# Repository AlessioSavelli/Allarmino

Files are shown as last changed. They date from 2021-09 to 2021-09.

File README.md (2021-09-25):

# Futura Elettronica
Progetti disponibili :
-FW Allarmino
-HW Allarmino

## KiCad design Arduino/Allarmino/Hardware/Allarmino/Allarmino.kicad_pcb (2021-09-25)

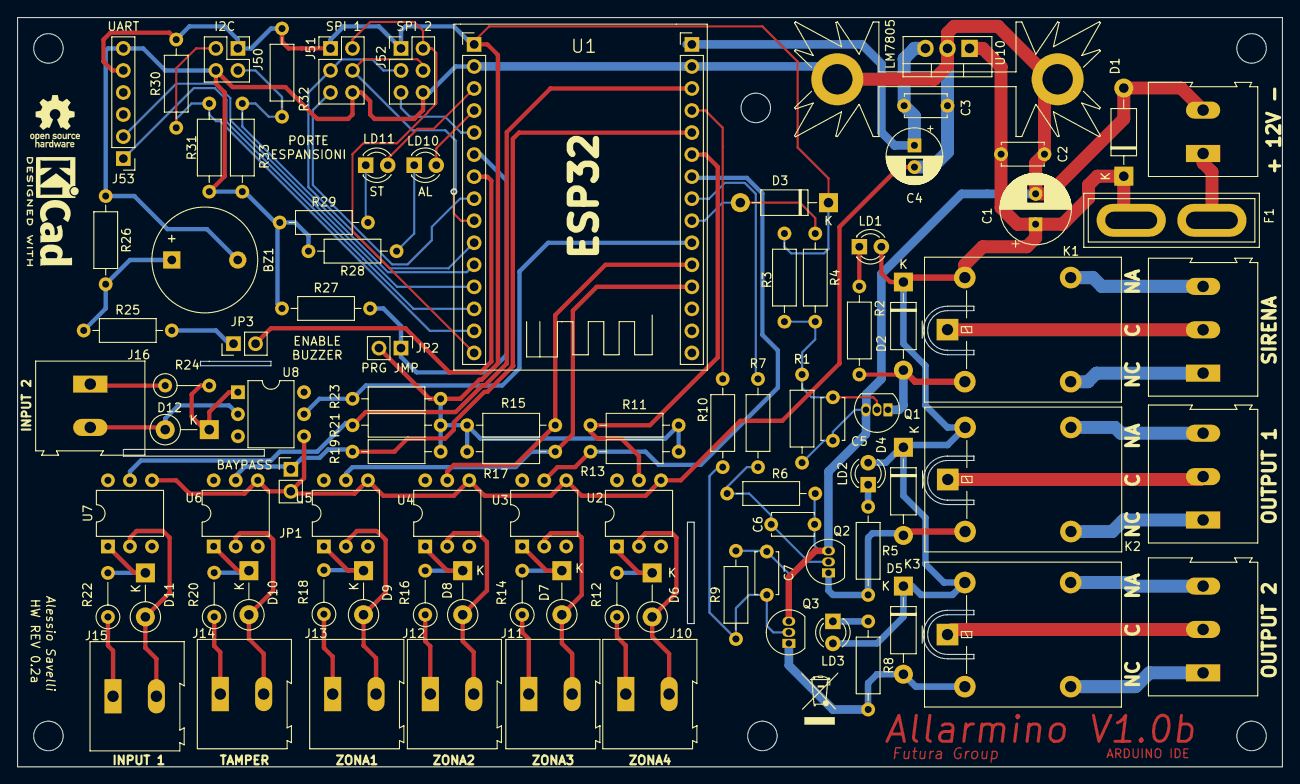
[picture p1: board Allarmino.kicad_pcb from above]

Board: 2 copper layers, 145.8 x 86.4 mm, 93 parts (0 on the bottom side), 71 nets.

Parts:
BZ1: Buzzer; Buzzer_12x9.5RM7.6
C1: 100uF; CP_Radial_D8.0mm_P3.50mm
C2, C3: 100nF; C_Disc_D4.7mm_W2.5mm_P5.00mm
C4: 10uF; CP_Radial_D6.3mm_P2.50mm
C5, C6, C7: 10nF; C_Disc_D4.7mm_W2.5mm_P5.00mm
D1, D2, D3, D4, D5: 1N4007; D_DO-41_SOD81_P10.16mm_Horizontal
D6, D7, D8, D9, D10, D11, D12: 1N4007; D_DO-41_SOD81_P5.08mm_Vertical_KathodeUp
F1: 0.8A; Fuse_Blade_ATO_directSolder
J1: Supply; TerminalBlock_Altech_AK300-2_P5.00mm
J2: Sirena; TerminalBlock_Altech_AK300-3_P5.00mm
J3: Output1; TerminalBlock_Altech_AK300-3_P5.00mm
J4: Output2; TerminalBlock_Altech_AK300-3_P5.00mm
J10: ZONA4; TerminalBlock_Altech_AK300-2_P5.00mm
J11: ZONA3; TerminalBlock_Altech_AK300-2_P5.00mm
J12: ZONA2; TerminalBlock_Altech_AK300-2_P5.00mm
J13: ZONA1; TerminalBlock_Altech_AK300-2_P5.00mm
J14: TAMPER; TerminalBlock_Altech_AK300-2_P5.00mm
J15: INPUT1; TerminalBlock_Altech_AK300-2_P5.00mm
J16: INPUT2; TerminalBlock_Altech_AK300-2_P5.00mm
J50: I2C; PinHeader_2x02_P2.54mm_Vertical
J51: SPI_1; PinHeader_2x03_P2.54mm_Vertical
J52: SPI_2; PinHeader_2x03_P2.54mm_Vertical
J53: UART; PinHeader_1x06_P2.54mm_Vertical
JP1: BAYPASS; PinHeader_1x02_P2.54mm_Vertical
JP2: PRG_JMP; PinHeader_1x02_P2.54mm_Vertical
JP3: BUZZ_ENABLE; PinHeader_1x02_P2.54mm_Vertical
K1, K2, K3: VR15M121C; Relay_SPDT_Omron-G5LE-1
LD1, LD2, LD3: GREEN; LED_D3.0mm
LD10: YELLOW; LED_D3.0mm
LD11: RED; LED_D3.0mm
Q1, Q2, Q3: BC546; TO-92_Inline
R1, R6, R9, R11, R13, R15, R17, R19, R21, R23, R27: 100K; R_Axial_DIN0207_L6.3mm_D2.5mm_P10.16mm_Horizontal
R2, R5, R8: 1.2K; R_Axial_DIN0207_L6.3mm_D2.5mm_P10.16mm_Horizontal
R3: 5.6K; R_Axial_DIN0207_L6.3mm_D2.5mm_P10.16mm_Horizontal
R4: 820; R_Axial_DIN0207_L6.3mm_D2.5mm_P10.16mm_Horizontal
R7, R10: 4.7k; R_Axial_DIN0207_L6.3mm_D2.5mm_P10.16mm_Horizontal
R12, R14, R16, R18, R20, R22, R24: 1K; R_Axial_DIN0207_L6.3mm_D2.5mm_P5.08mm_Vertical
R25: 120; R_Axial_DIN0207_L6.3mm_D2.5mm_P10.16mm_Horizontal
R26: 10K; R_Axial_DIN0207_L6.3mm_D2.5mm_P10.16mm_Horizontal
R28, R29: 180; R_Axial_DIN0207_L6.3mm_D2.5mm_P10.16mm_Horizontal
R30, R31, R32, R33: 2.2K; R_Axial_DIN0207_L6.3mm_D2.5mm_P10.16mm_Horizontal
U1: ESP32_LEFT; PinHeader_1x15_P2.54mm_Vertical
U2, U3, U4, U5, U6, U7, U8: 4N25; DIP-6_W7.62mm
U10: LM7805; TO-220-3_Vertical
U_1: ESP32_RIGHT; PinHeader_1x15_P2.54mm_Vertical

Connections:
+3V3: D3.1, J50.1, J51.1, J52.1, J53.5, JP2.2, R3.2, R11.2, R13.2, R15.2, R17.2, R19.2, R21.2, R23.2, R30.2, R32.1, U_1.1
+5V: C3.1, C4.1, U1.1, U10.3
+12V: C1.1, C2.1, D1.1, D2.1, D4.1, D5.1, F1.1, K1.5, K2.5, K3.5, LD1.2, LD2.2, LD3.2, U10.1
/D2: LD10.2, U_1.4
/D12: R10.1, U1.4
/D13: R21.1, U1.3, U7.5
/D14: JP1.1, R19.1, U1.5, U6.5
/D15: LD11.2, U_1.3
/D25: R7.1, U1.8
/D26: R13.1, U1.7, U3.5
/D27: R11.1, U1.6, U2.5
/D32: R23.1, U1.10, U8.5
/D33: D3.2, R4.2, U1.9
/D34: R17.1, U1.12, U5.5
/D35: R15.1, U1.11, U4.5
/RX0: J53.2, U_1.12
/TX0: J53.1, U_1.13
BUZZER: JP3.2, U_1.7
CLK: J51.4, J52.4, U_1.9
CONFIG_JMP: JP2.1, R27.2, U_1.6
CS1: J51.5, U_1.8
CS2: J52.5, U_1.5
GND: BZ1.2, C1.2, C2.2, C3.2, C4.2, C5.2, C6.2, C7.2, D1.2, J1.2, J50.4, J51.6, J52.6, J53.6, JP1.2, Q1.3, Q2.3, Q3.3, R1.2, R6.2, R9.2, R26.1, R27.1, R28.1, R29.1, R31.1, R33.2, U1.2, U2.4, U3.4, U4.4, U5.4, U6.4, U7.4, U8.4, U10.2, U_1.2
MISO: J51.3, J52.3, U_1.10
MOSI: J51.2, J52.2, U_1.15
unnamed: BZ1.1, R25.1, R26.2
unnamed: C5.1, Q1.2, R1.1, R3.1, R4.1
unnamed: C6.1, Q2.2, R6.1, R7.2
unnamed: C7.1, Q3.2, R9.1, R10.2
unnamed: D2.2, K1.2, Q1.1, R2.2
unnamed: D4.2, K2.2, Q2.1, R5.2
unnamed: D5.2, K3.2, Q3.1, R8.2
unnamed: D6.1, R12.2, U2.1
unnamed: D6.2, J10.2, U2.2
unnamed: D7.1, R14.2, U3.1
unnamed: D7.2, J11.2, U3.2
unnamed: D8.1, R16.2, U4.1
unnamed: D8.2, J12.2, U4.2
unnamed: D9.1, R18.2, U5.1
unnamed: D9.2, J13.2, U5.2
unnamed: D10.1, R20.2, U6.1
unnamed: D10.2, J14.2, U6.2
unnamed: D11.1, R22.2, U7.1
unnamed: D11.2, J15.2, U7.2
unnamed: D12.1, R24.2, U8.1
unnamed: D12.2, J16.2, U8.2
unnamed: F1.2, J1.1
unnamed: J2.1, K1.3
unnamed: J2.2, K1.1
unnamed: J2.3, K1.4
unnamed: J3.1, K2.3
unnamed: J3.2, K2.1
unnamed: J3.3, K2.4
unnamed: J4.1, K3.3
unnamed: J4.2, K3.1
unnamed: J4.3, K3.4
unnamed: J10.1, R12.1
unnamed: J11.1, R14.1
unnamed: J12.1, R16.1
unnamed: J13.1, R18.1
unnamed: J14.1, R20.1
unnamed: J15.1, R22.1
unnamed: J16.1, R24.1
unnamed: JP3.1, R25.2
unnamed: LD1.1, R2.1
unnamed: LD2.1, R5.1
unnamed: LD3.1, R8.1
unnamed: LD10.1, R28.2
unnamed: LD11.1, R29.2
SCL: J50.3, R30.1, R31.2, U_1.14
SDA: J50.2, R32.2, R33.1, U_1.11

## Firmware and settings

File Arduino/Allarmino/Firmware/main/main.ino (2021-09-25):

/*
   Titolo : Allarmino - Elettronica IN
   Hardware : ESP32
   Ver : 1.0V b
   Data : 30/06/2021
   Autore : Alessio Savelli by Futura Group
*/
#include "Macro.h"
#include "setup.h"
#include "Global.h"
#include "myWiFi.h"
#include "IO_GESTURE.h"
#include "Allarme.h"

//Creiamo un task parallelo sul secondo core dell'esp32 che gestisce la connessione WiFi

TaskHandle_t WiFiTask1;
void loop2(void * pvParameters );
void setup() {
  Serial.begin(115200);
  Serial.println("START-UP");

  pinMode(SIRENA, OUTPUT);
  digitalWrite(SIRENA, SIRENA_OFF);
  pinMode(OUTPUT1, OUTPUT);
  pinMode(OUTPUT2, OUTPUT);

  pinMode(LED_AL, OUTPUT);
  pinMode(LED_ST, OUTPUT);
  pinMode(BUZZER, OUTPUT);

  pinMode(INPUT1  , INPUT);
  pinMode(INPUT2  , INPUT);

  pinMode(ZONA1  , INPUT);
  pinMode(ZONA2  , INPUT);
  pinMode(ZONA3  , INPUT);
  pinMode(ZONA4  , INPUT);

  pinMode(TAMPER  , INPUT);


  xTaskCreatePinnedToCore(
    loop2,           /* Task function. */
    "WiFiTask1",     /* name of task. */
    10000,           /* Stack size of task */
    NULL,            /* parameter of the task */
    1,               /* priority of the task */
    &WiFiTask1,      /* Task handle to keep track of created task */
    0);              /* pin task to core 0 */

}
unsigned int main_timer = 0;
void loop() {//Run on core task 1
  output_loop();     //Gestisce il pilotaggio degli output
  input_loop();      //Gestisce la lettura di tutti gli input della scheda

  event_io_loop();   //Gestisce gli eventi associati ai vari Input e Output
  flag_trg_loop();   //Gestisce il triggering degli eventi su flag interni del software - solo quelli che possono essere modificati da più operazioni che si svolgono in contemporanea

  loop_allarme();    //Gestisce l'algorittimo di anti intrusione
  bool b = false;
  if (stato_key_allarme == ST_ATTIVA_ALLARME)b = true;
  digitalWrite(LED_ST, b);
  //Serial.println(stato_input2);

}

void loop2(void * pvParameters ) {//Run on core task 0
  for (;;) {
    WiFiLoop();//Gestisce tutti gli eventi wifi e le comunicazioni via internet
    delay(1);
  }
}

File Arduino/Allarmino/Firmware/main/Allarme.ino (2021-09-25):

void loop_allarme() {




  static unsigned long allarme_timer0 = 0;
  static unsigned long allarme_timer1 = 0;

  static unsigned int allarme_counter0 = 0;

  static byte mask_esclusioni = 0; //Maschera esclusioni permanenti per il ciclo dell'allarme
  static byte mask_temp_esclusioni = 0; //Maschera esclusioni temporanee

  static byte hold_allarm_sensor = 0; // Salva i sensori che vanno in allarme nel ciclo della sirena

  static byte map_sensor = 0; // Mappa stato sensori attuale

  String notify_message_allarme = "";


  if (stato_key_allarme == ST_DISATTIVA_ALLARME && ST_allarme != ST_ALLARME_WAIT_KEY) {
    ST_allarme = ST_ALLARME_RESET_ALL; // Resetta l'algorittimo dell'allarme
  } else if (stato_key_allarme == ST_ATTIVA_ALLARME && ST_allarme == ST_ALLARME_WAIT_KEY) {
    ST_allarme = ST_ALLARME_TEMPO_DI_USCITA; // fa partire l'algorittimo dell'allarme
    START_TIMER(allarme_timer0); // fa partire il timer per il tempo d'ingresso
    START_TIMER(allarme_timer1); // fa partire il timer per il beep del buzzer
  }
  if (ST_allarme != ST_ALLARME_WAIT_KEY) Serial.println(ST_allarme);
  switch (ST_allarme) {
    case ST_ALLARME_WAIT_KEY:
      stato_allarme == RIPOSO;
      break;
    case ST_ALLARME_TEMPO_DI_USCITA:
      if (IS_DELAYED(allarme_timer0, ALLARME_ON_DELAYED)) { // Attende che sia passato il tempo d'ingresso
        digitalWrite(BUZZER, LOW);
        ST_allarme = ST_ALLARME_AUTO_ESCLUSIONI;
      } else { // fa fare un beep del buzzer
        if (IS_DELAYED(allarme_timer1, 350)) {
          digitalWrite(BUZZER, !digitalRead(BUZZER)); //Fa fare il beep del buzzer
          START_TIMER(allarme_timer1); // Resetta il timer per il beep
        }
      }
      break;
    case ST_ALLARME_AUTO_ESCLUSIONI:
      //popola la mappa dei sensori in allarme
      map_allarm_sensor(&map_sensor);
      //mappo temporaneamente la maschera di escludibilità zone
      mask_esclusioni = ZONA1_ESCLUDIBILE;
      mask_esclusioni = mask_esclusioni | ( ZONA2_ESCLUDIBILE << 1);
      mask_esclusioni = mask_esclusioni | ( ZONA3_ESCLUDIBILE << 2);
      mask_esclusioni = mask_esclusioni | ( ZONA4_ESCLUDIBILE << 3);
      mask_esclusioni = mask_esclusioni | ( TAMPER_ESCLUDIBILE << 4);
      //Salvo la maschera dei sensori autoescludibili applicando la maschera temporanea alla mappa dei sensori
      mask_esclusioni = map_sensor & mask_esclusioni; // Salvo la maschera dei sensori in allamre che possono andare in autoesclusione
      //Metto gli stati dei sensori in modalità esclusa
      if (GETBIT8(mask_esclusioni, BIT_ZONE1))stato_zona1 = AUTOESCLUSIONE; // indica che la zona è esclusa. il valore binario è la maschera di controllo esclusione di zona
      if (GETBIT8(mask_esclusioni, BIT_ZONE2))stato_zona2 = AUTOESCLUSIONE; // indica che la zona è esclusa. il valore binario è la maschera di controllo esclusione di zona
      if (GETBIT8(mask_esclusioni, BIT_ZONE3))stato_zona3 = AUTOESCLUSIONE; // indica che la zona è esclusa. il valore binario è la maschera di controllo esclusione di zona
      if (GETBIT8(mask_esclusioni, BIT_ZONE4))stato_zona4 = AUTOESCLUSIONE; // indica che la zona è esclusa. il valore binario è la maschera di controllo esclusione di zona

      if (GETBIT8(mask_esclusioni, BIT_TAMPER))stato_tamper = AUTOESCLUSIONE;


      if (map_sensor != mask_esclusioni) { //Allarme non attivabile
        ST_allarme = ST_ALLARME_ALLERT_BUZZER1; // Va alla segnalazione allarme non attivabile
      } else {
        ST_allarme = ST_ALLARME_ALLERT_BUZZER2; // Va alla segnalazione allarme attivabile
      }
     /* Serial.println("----CHECK----");
      Serial.print("MASK ESCLUSIONI : ");
      Serial.println(mask_esclusioni, HEX);
      Serial.print("MAPPA SENSORI : ");
      Serial.println(map_sensor, HEX);
      Serial.println("-----------");*/
      RESET_COUNTER(allarme_counter0); //Resetto il counter per i beep
      START_TIMER(allarme_timer1); // Resetta il timer per il beep
      break;
    case ST_ALLARME_ALLERT_BUZZER1://Allarme non attivabile
      //fa 3 beep per segnalare l'errore
      if (allarme_counter0 >= ALLARME_CICLI_BEEP(3)) {
        ST_allarme = ST_ALLARME_RESET_ALL;
        //Disattiva la chiave
        trg_change_key = true;
        new_st_key = ST_DISATTIVA_ALLARME;
        //invio notifica di non attivabilità
        notify_message_allarme = "!! Allarme non attivabile !!.\n";
        notify_message_allarme += string_zone_builder();
        notify_message_allarme += "ALLARME NON ATTIVA";

        send_telegram_message(notify_message_allarme);
      } else if (IS_DELAYED(allarme_timer1, 1000)) {
        digitalWrite(BUZZER, !digitalRead(BUZZER)); //Fa fare il beep del buzzer
        allarme_counter0++;
        START_TIMER(allarme_timer1); // Resetta il timer per il beep
      }
      break;
    case ST_ALLARME_ALLERT_BUZZER2://Allarme attivabile , controlla lo stato delle esclusioni
      if (CHECKBITMASK(mask_esclusioni, BUILDBITMASK8(0, 0, 0, 0, 1, 1, 1, 1))) { // Beep per indicare un sensore escluso
        if (allarme_counter0 == 0 && IS_DELAYED(allarme_timer1, 500)) { // Aspetta 500ms prima di iniziare la sequenza dei beep
          allarme_counter0++;
          digitalWrite(BUZZER, !digitalRead(BUZZER)); //Fa fare il beep del buzzer
          START_TIMER(allarme_timer1); // Resetta il timer per il beep
        } else if (allarme_counter0 <= ALLARME_CICLI_BEEP(2) && IS_DELAYED(allarme_timer1, 250)) {// Fa 2 beep veloci 250ms
          allarme_counter0++;
          digitalWrite(BUZZER, !digitalRead(BUZZER)); //Fa fare il beep del buzzer
          START_TIMER(allarme_timer1); // Resetta il timer per il beep
        } else { // se allarme_counter0>4 allora passa all'allarte successivo

          notify_message_allarme = "!! Alcune zone escluse !!.\n";
          notify_message_allarme += string_zone_builder();
          send_telegram_message(notify_message_allarme);

          RESET_COUNTER(allarme_counter0); //Resetta il counter per contare i beep
          START_TIMER(allarme_timer1); // Resetta il timer per il beep
          ST_allarme = ST_ALLARME_ALLERT_BUZZER3; //Si sposta all'allert successivo
        }
      } else {
        ST_allarme = ST_ALLARME_ALLERT_BUZZER3; //Si sposta all'allert successivo senza segnalare nulla
      }
      break;
    case ST_ALLARME_ALLERT_BUZZER3:
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
